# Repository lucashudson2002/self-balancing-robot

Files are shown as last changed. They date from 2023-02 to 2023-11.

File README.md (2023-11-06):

# Self Balancing Robot
<p > 
    This is a self balancing robot made with esp32, that is, a robot with 2 wheels that will have to balance itself. <br>
</p>

## 🔗 Summary

## 🗼 Bigweld

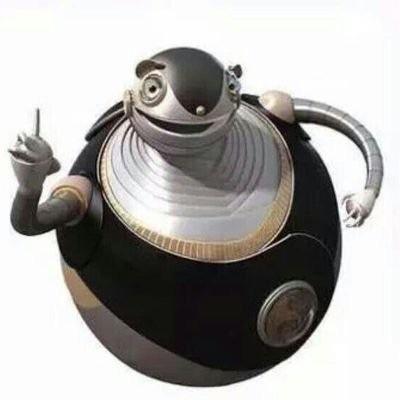
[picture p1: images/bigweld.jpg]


## 🎱 Cannonbolt

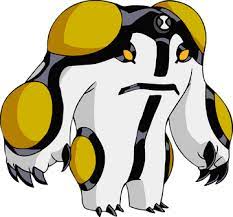
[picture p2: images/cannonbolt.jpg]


##  ✔️ Techniques and technologies

- ``Arduino``
- ``ESP32``
- ``C``
- ``C++``
- ``POO``
- ``PID``
- ``Motors``
- ``Sensors``

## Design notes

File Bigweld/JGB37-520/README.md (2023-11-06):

# Bigweld JGB37-520

## 🛠️ Bill of materials (V1)

### Mechanical parts

- Motor JGB37-520 6V 1000RPM w/ encoder - 2 un.
- Bracket for JGB37-520 w/ 6 screw M3x8mm - 2un.
- Pololu Silicone Tire Pair 60×8mm/70×8mm - 1un.
- Screw M4x75mm - 4un.
- Nut M4 - 20un.
- Screw M3x10mm - 4un.
- Screw M3x8mm - 8un.
- Nut M3 - 12 un.
- Screw M2x8mm - 8un.
- Nut M2 - 8un.

### Laser cut parts (acrylic)

- Base.stl - 1un.
- Cover.stl - 1 un.

### 3D printed parts (PLA)

- Wheel.stl - 2un.
- Support.stl - 2un.

### Electronic parts

- ESP32 30 Pins
- TB6612FNG
- MPU6050
- MINI 360
- Female Socket 1x40 - 2un.
- JST-2.54-6P - 2un.
- JST-2.54-2P - 1un.
- Switch on/off
- Lipo Battery

## 🛠️ Bill of materials (V2)

### Mechanical parts

### Laser cut parts (acrylic)

### 3D printed parts (PLA)

### Electronic parts

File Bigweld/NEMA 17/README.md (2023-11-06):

# Bigweld NEMA 17

## 🛠️ Bill of materials

### Mechanical parts

- NEMA 17 - 2 un.
- Pololu Silicone Tire Pair 60×8mm/70×8mm - 1un.
- Screw M4x75mm - 4un.
- Nut M4 - 20un.
- Screw M3x10mm - 12un.
- Screw M3x8mm - 8un.
- Nut M3 - 12 un.
- Screw M2x8mm - 8un.
- Nut M2 - 8un.

### Laser cut parts (acrylic)

- Base.stl - 1un.
- Cover.stl - 1 un.

### 3D printed parts (PLA)

- Wheel.stl - 2un.
- Support.stl - 2un.
- Bracket.stl - 2un.

### Electronic parts

- ESP32 30 Pins
- A4988 - 2un.
- MPU6050
- MINI 360 or MT3608
- Female Socket 1x40 - 2un.
- JST-2.54-6P - 2un.
- JST-2.54-2P - 1un.
- Switch on/off
- Lipo Battery

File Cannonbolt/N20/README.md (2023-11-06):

# Cannonbolt N20

## 🛠️ Bill of materials

### Mechanical parts

### Laser cut parts (acrylic)

### 3D printed parts (PLA)

### Electronic parts

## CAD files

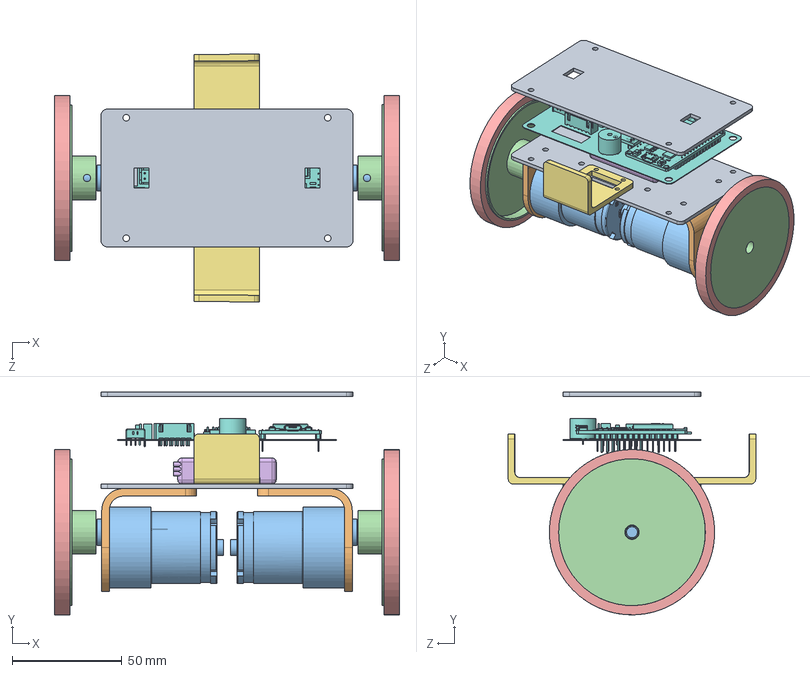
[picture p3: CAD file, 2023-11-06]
Bigweld/JGB37-520/v2/solid/robot.SLDASM
157.5 x 101.7 x 113.1 mm
base
bracket x 2
JGB37-520 x 2
wheel x 2
tire x 2
battery_300mah
support x 2
pcb
cover

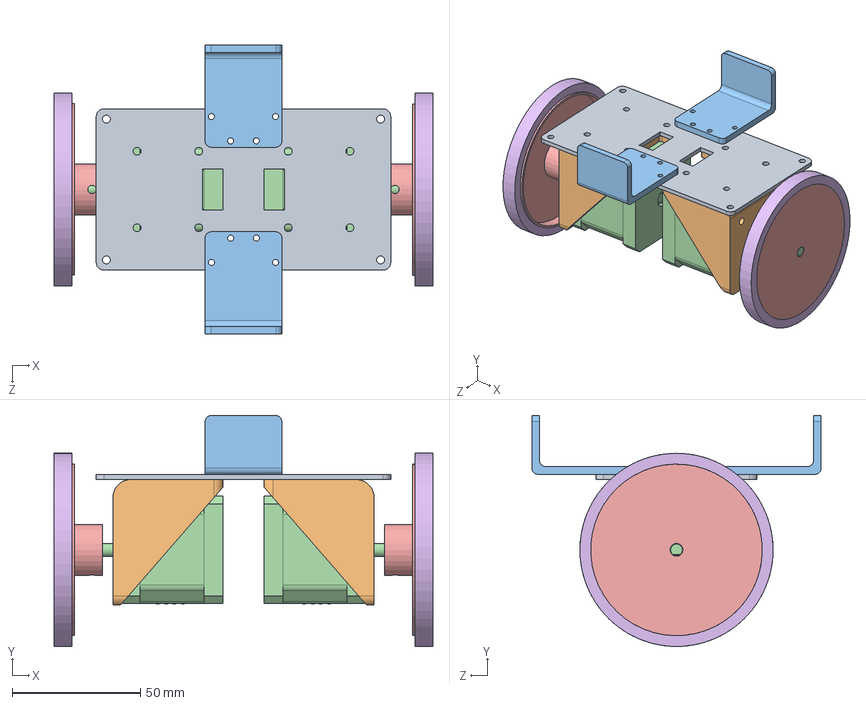
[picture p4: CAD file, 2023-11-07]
Bigweld/NEMA 17/solid/robot.SLDASM
148.0 x 90.2 x 113.0 mm
base
bracket x 2
support x 2
NEMA17 x 2
wheel x 2
tire x 2

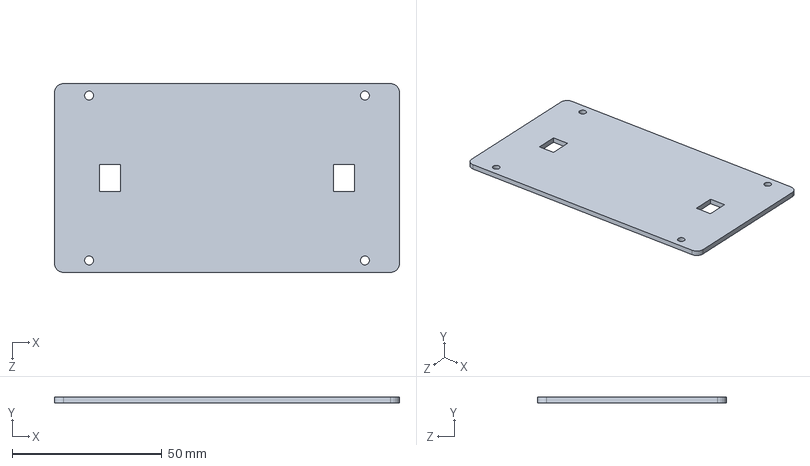
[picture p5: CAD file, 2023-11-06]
Bigweld/JGB37-520/v2/solid/cover.SLDPRT
115.1 x 2.00 x 63.0 mm

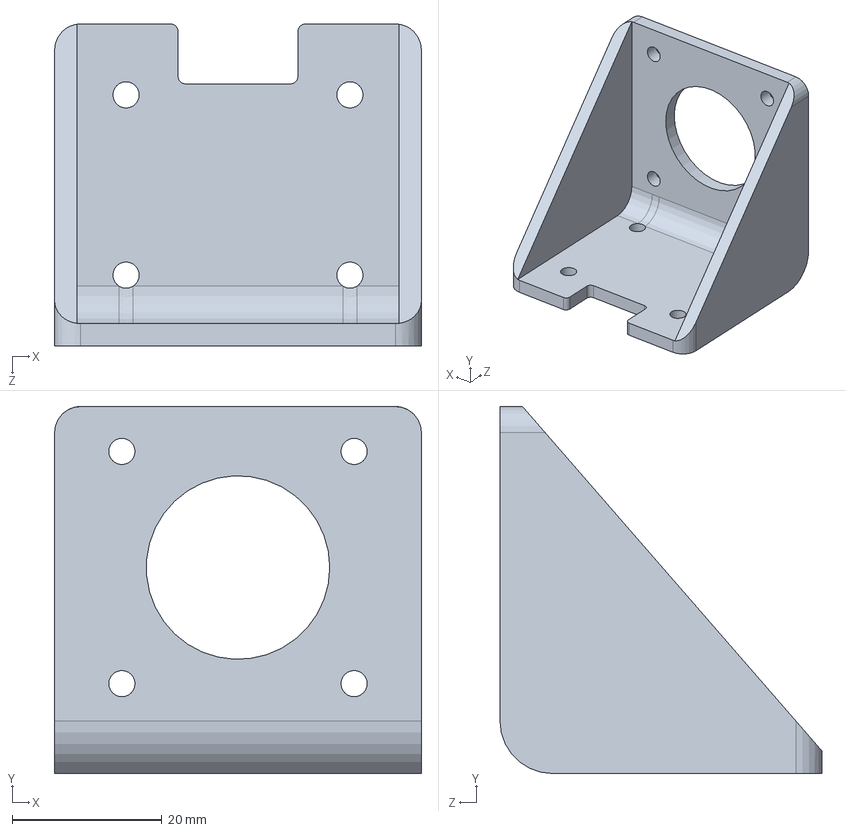
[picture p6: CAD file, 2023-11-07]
Bigweld/NEMA 17/solid/bracket.SLDPRT
49.0 x 49.0 x 43.0 mm

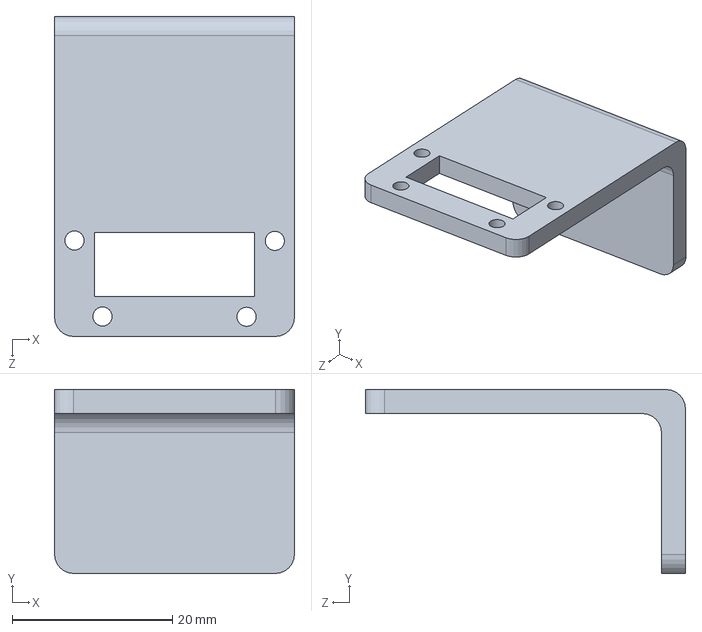
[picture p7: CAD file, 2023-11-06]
Bigweld/JGB37-520/v2/solid/support.SLDPRT
30.0 x 23.0 x 40.0 mm

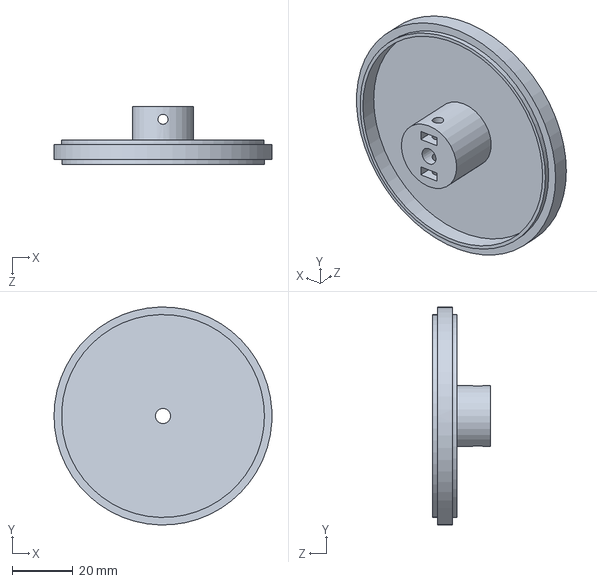
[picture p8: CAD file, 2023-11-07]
Bigweld/NEMA 17/solid/wheel.SLDPRT
72.0 x 72.0 x 19.0 mm

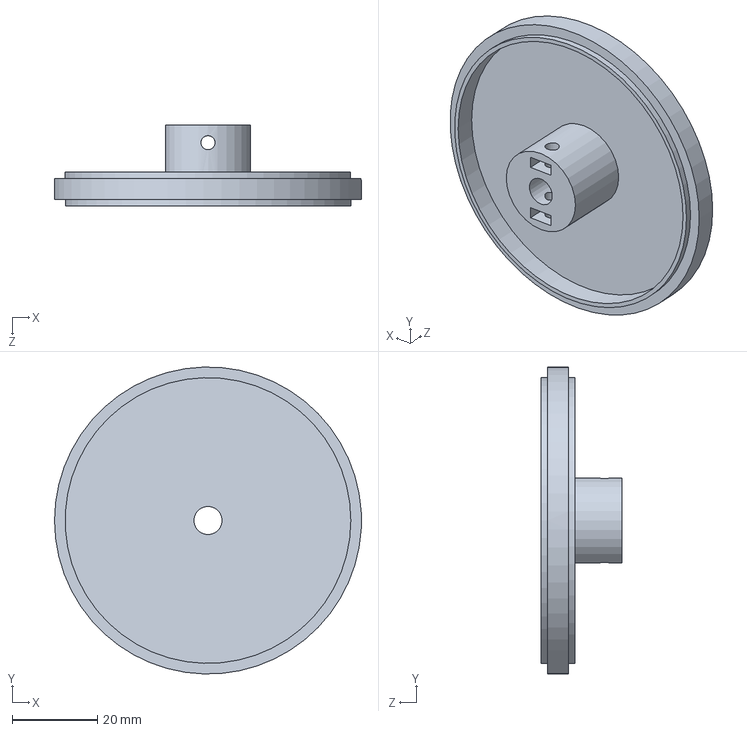
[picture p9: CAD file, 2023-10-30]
Bigweld/JGB37-520/v2/solid/wheel.SLDPRT
72.0 x 72.0 x 19.0 mm

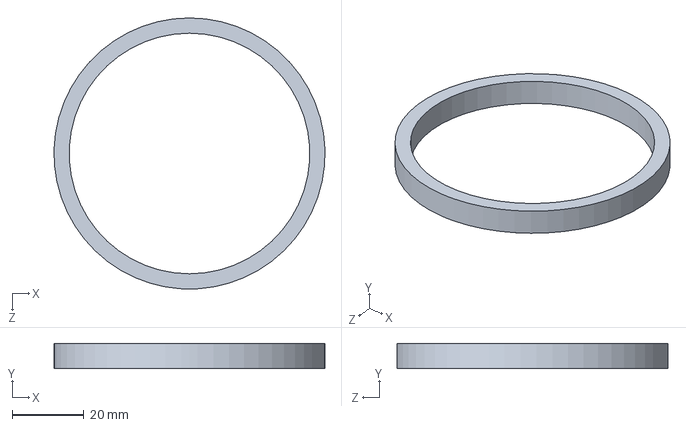
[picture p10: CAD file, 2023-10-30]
Bigweld/JGB37-520/v2/solid/tire.SLDPRT
75.5 x 7.00 x 75.5 mm

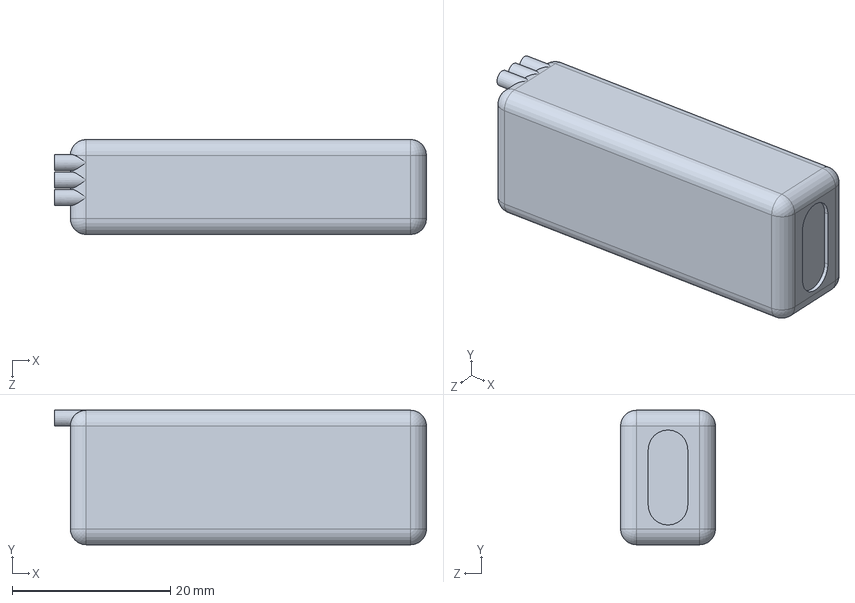
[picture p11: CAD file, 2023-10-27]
Bigweld/JGB37-520/v2/solid/battery_300mah.SLDPRT
47.0 x 17.0 x 12.0 mm

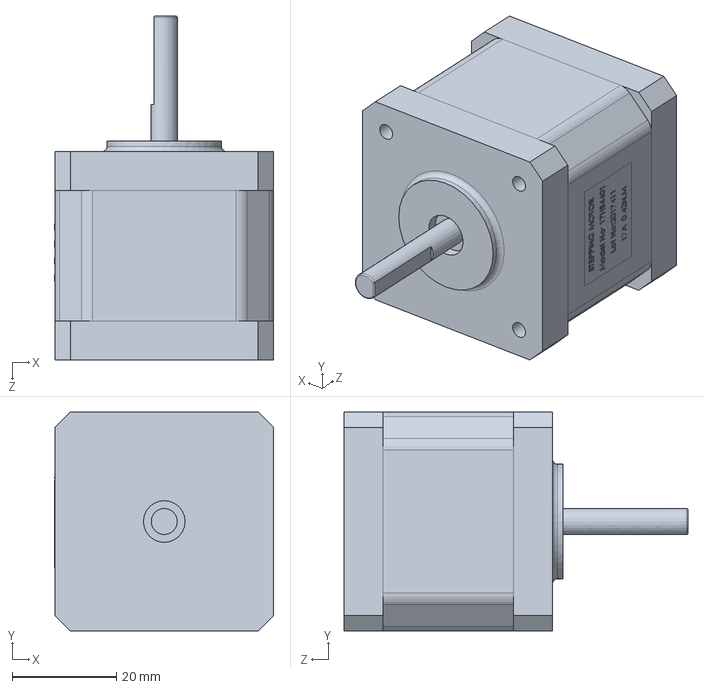
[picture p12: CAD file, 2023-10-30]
Bigweld/NEMA 17/solid/NEMA17.SLDPRT
42.1 x 42.0 x 66.0 mm

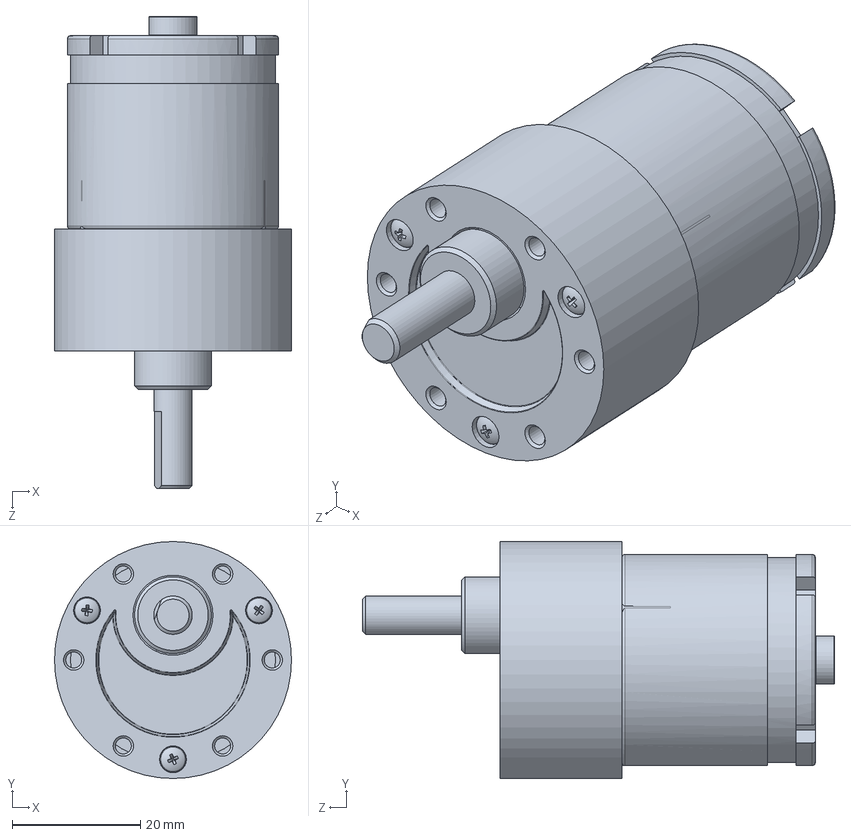
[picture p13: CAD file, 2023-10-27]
Bigweld/JGB37-520/v2/solid/JGB37-520.SLDPRT
37.0 x 37.0 x 73.7 mm

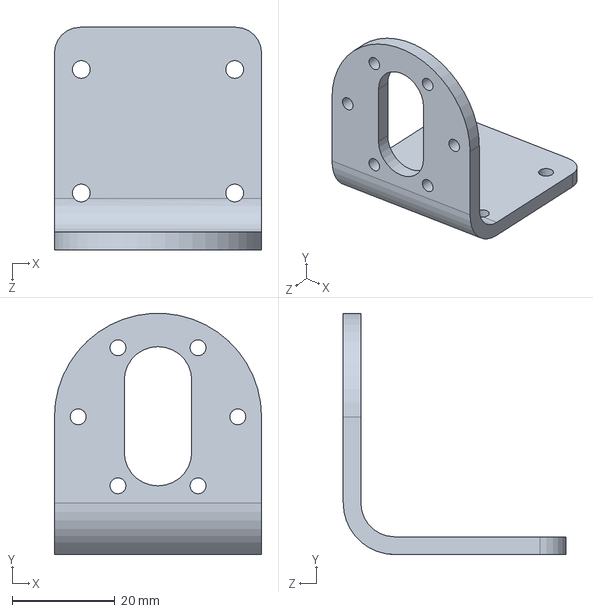
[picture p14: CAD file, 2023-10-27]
Bigweld/JGB37-520/v2/solid/bracket.SLDPRT
40.3 x 47.0 x 43.3 mm

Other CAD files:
Bigweld/NEMA 17/solid/support.SLDPRT
Bigweld/JGB37-520/v2/solid/base.SLDPRT
Bigweld/NEMA 17/solid/base.SLDPRT
Bigweld/NEMA 17/solid/cover.SLDPRT
Bigweld/JGB37-520/v1/solid/base.SLDPRT
Bigweld/JGB37-520/v1/solid/cover.SLDPRT
Bigweld/JGB37-520/v1/solid/robot.SLDASM
Cannonbolt/N20/altium/placa.DXF
Cannonbolt/N20/solid/base.SLDPRT
Cannonbolt/N20/solid/motor_bracket_encoder.SLDPRT
Cannonbolt/N20/solid/placa.SLDPRT
Cannonbolt/N20/solid/robot.SLDASM
Cannonbolt/N20/solid/tire.SLDPRT
Cannonbolt/N20/solid/wheel.SLDPRT
Cannonbolt/N20/solid/wheel2.SLDPRT
Cannonbolt/N20/solid/wheel2.STL

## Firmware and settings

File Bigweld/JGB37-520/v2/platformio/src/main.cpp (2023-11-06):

#include <Arduino.h>
#include <Kalman.h>
#include "pid.h"
#include "motor.h"
#include "i2cMPU6050.h"
#include "bluetooth.h"

#define LED 2
#define BUZZER 4

// MPU6050 e KALMAN
Point3lf acc, gyro;
double pitch;
double gyroY;
Kalman KalmanY;
uint32_t timer;
double dt;

// CONTROLE PID
double Input, Output, Setpoint=0;
PID pid(&Input, &Output, &Setpoint);

void setup() {
    Serial.begin(115200);

    SerialBT.begin("Bigweld");

    pinMode(LED, OUTPUT);
    pinMode(BUZZER, OUTPUT);

    pinMode(PWMA, OUTPUT);
    pinMode(AIN2, OUTPUT);
    pinMode(AIN1, OUTPUT);
    pinMode(STBY, OUTPUT);
    pinMode(BIN1, OUTPUT);
    pinMode(BIN2, OUTPUT);
    pinMode(PWMB, OUTPUT);

    ledcAttachPin(PWMA, 0);
    ledcSetup(0, 19500, 12);
    ledcAttachPin(PWMB, 1);
    ledcSetup(1, 19500, 12);

    digitalWrite(STBY, HIGH);

    ledcWrite(0, 0);
    ledcWrite(1, 0);

    pinMode(ENA1, INPUT);
    pinMode(ENA2, INPUT);
    pinMode(ENB1, INPUT);
    pinMode(ENB2, INPUT);

    attachInterrupt(ENA1, encoderA, CHANGE);
    attachInterrupt(ENB1, encoderB, CHANGE);

    init_mpu();

    acc = readAccel();
    gyro = readGyro();
    pitch = atan(-acc.x / sqrt(acc.y * acc.y + acc.z * acc.z)) * RAD_TO_DEG;
    Input = pitch;
    KalmanY.setAngle(Input);

    pid.setOutputLimits(-4095, 4095);

    timer = micros();
}

void loop() {
    if (readBluetooth())
        pid.setTunings(jsonPID["kp"], jsonPID["ki"], jsonPID["kd"]);
    
    sendBluetooth(Input);

    acc = readAccel();
    gyro = readGyro();
    pitch = atan(-acc.x / sqrt(acc.y * acc.y + acc.z * acc.z)) * RAD_TO_DEG;
    gyroY = gyro.y / 131.0;

    dt = (double)(micros() - timer)/1000000;
    timer = micros();

    Input = KalmanY.getAngle(pitch, gyroY, dt);

    pid.compute();

    int pwm = map(abs(Output), 0, 4095, MOTOR_MIN, 4095);
    if (Output > 0)
        forward(pwm, pwm);
    else if (Output < 0)
        backward(pwm, pwm);
    else
        brake();

    // Serial.println(pwm);

    // Serial.printf("%lf\t%f\n", pitch, Input);
}

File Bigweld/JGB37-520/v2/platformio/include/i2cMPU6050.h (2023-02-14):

#pragma once
#include <Wire.h>

const uint8_t IMUAddress = 0x68;
const uint16_t I2C_TIMEOUT = 1000;

uint8_t i2cWrite(uint8_t registerAddress, uint8_t *data, uint8_t length, bool sendStop) {
  Wire.beginTransmission(IMUAddress);
  Wire.write(registerAddress);
  Wire.write(data, length);
  uint8_t rcode = Wire.endTransmission(sendStop);
  if (rcode) {
    //Serial.print(F("i2cWrite failed: "));
    //Serial.println(rcode);
  }
  return rcode;
}

uint8_t i2cWrite(uint8_t registerAddress, uint8_t data, bool sendStop) {
  return i2cWrite(registerAddress, &data, 1, sendStop);
}

uint8_t i2cRead(uint8_t registerAddress, uint8_t *data, uint8_t nbytes) {
  uint32_t timeOutTimer;
  Wire.beginTransmission(IMUAddress);
  Wire.write(registerAddress);
  uint8_t rcode = Wire.endTransmission(false);
  if (rcode) {
    //Serial.print(F("i2cRead failed: "));
    //Serial.println(rcode);
    return rcode;
  }
  Wire.requestFrom(IMUAddress, nbytes, (uint8_t)true);
  for (uint8_t i = 0; i < nbytes; i++) {
    if (Wire.available())
      data[i] = Wire.read();
    else {
      timeOutTimer = micros();
      while (((micros() - timeOutTimer) < I2C_TIMEOUT) && !Wire.available());
      if (Wire.available())
        data[i] = Wire.read();
      else {
        //Serial.println(F("i2cRead timeout"));
        return 5;
      }
    }
  }
  return 0;
}

uint8_t i2c_data[14];

struct Point3lf{
  double x, y, z;
};

void init_mpu(){
  Wire.begin();

  #if ARDUINO >= 157
    Wire.setClock(400000UL);
  #else
    TWBR = ((F_CPU/400000UL) - 16) / 2;
  #endif

  i2c_data[0] = 7;
  i2c_data[1] = 0x00;
  i2c_data[2] = 0x00;
  i2c_data[3] = 0x00;

  while(i2cWrite(0x19, i2c_data, 4, false));

  while(i2cWrite(0x6B, 0x01, true));

  while(i2cRead(0x75, i2c_data, 1));

  if(i2c_data[0] != 0x68){
    //Serial.print("Erro. Placa desconhecida\n");
    while(1){
      //Serial.print("Erro. Conecte a MPU6050 no barramento i2c\n");
    }
  }
}

Point3lf readAccel(){
  Point3lf acc;
  while(i2cRead(0x3B, i2c_data, 14));
  acc.x = (int16_t)((i2c_data[0] << 8) | i2c_data[1]);
  acc.y = (int16_t)((i2c_data[2] << 8) | i2c_data[3]);
  acc.z = (int16_t)((i2c_data[4] << 8) | i2c_data[5]);
  return acc;
}

Point3lf readGyro(){
  Point3lf gyro;
  while(i2cRead(0x3B, i2c_data, 14));
  gyro.x = (int16_t)((i2c_data[8] << 8) | i2c_data[9]);
  gyro.y = (int16_t)((i2c_data[10] << 8) | i2c_data[11]);
  gyro.z = (int16_t)((i2c_data[12] << 8) | i2c_data[13]);
  return gyro;
}

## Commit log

2023-01-23 adding components in sch
    [PCB1.PcbDoc, PCB_Project.PrjPcb, Sheet1.SchDoc]
2023-02-14 check electronic part
    [PCB1.PcbDoc, PCB_Project.PrjPcb, Sheet1.SchDoc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]
2023-02-14 finish fritzing
    [equilibrista.fzz]
2023-05-05 updating project
    [project.PrjPcb]
2023-10-26 starting new robot mechanics
    [JGB37-520.SLDPRT, base.SLDPRT, equilibrista.fzz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]
2023-10-27 finishing mechanics
    [JGB37-520.SLDPRT, base.SLDPRT, mancal.SLDPRT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]
2023-10-27 adding battery
    [bateria_300mah.SLDPRT, robo.SLDASM]
2023-10-30 finishing pcb
    [project.PrjPcb, schematic.SchDoc]
2023-10-30 adding pcb to solid
    [base.SLDPRT, pneu.SLDPRT, robo.SLDASM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]
2023-10-30 organizing files and versions
    [JGB37-520.SLDPRT, NEMA17.SLDPRT, base.SLDPRT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]
2023-10-31 adding tampa
    [mancal.SLDPRT, robo.SLDASM, tampa.SLDPRT]
2023-11-06 many changes
    [JGB37-520.SLDPRT, NEMA17.SLDPRT, base.SLDPRT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]
2023-11-07 finsishing sch Bigweld NEMA17
    [schematic.SchDoc]
2023-11-07 improving mechanics Bigweld NEMA17
    [base.SLDPRT, bracket.SLDPRT, robot.SLDASM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]
2024-01-02 finishing pcbs
    [base.SLDPRT, bracket.SLDPRT, esp32.SchDoc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]
